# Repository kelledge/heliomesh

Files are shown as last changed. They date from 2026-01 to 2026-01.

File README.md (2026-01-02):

# Heliomesh


[Documentation](https://kelledge.github.io/heliomesh/)

Heliomesh is a growing collection of PCB designs that enable anyone to build robust solar-power
Meshtastic nodes.

As fun as it is to solder up a solution, these often end up being the weak point of any solution.
This project aims to provide fully integrated solutions that any one can order and pairs nicely
with the existing range of Meshtastic devices and enclosures.

## Contibuting
TODO

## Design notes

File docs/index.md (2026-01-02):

# Project Docs

## Boards
  - [xiao-harbor-breeze-60lm](projects/xiao-harbor-breeze-60lm/index.md)

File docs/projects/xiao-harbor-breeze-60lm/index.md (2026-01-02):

<script type="module" src="https://ajax.googleapis.com/ajax/libs/model-viewer/4.0.0/model-viewer.min.js"></script>
<script type="module" src="../../kicanvas.js"></script>

# XIAO Harbor Breeze 60 Lumen

## Documentation

### 3D Model
<model-viewer alt="" src="../../assets/projects/xiao-harbor-breeze-60lm/xiao-harbor-breeze-60lm-3D.glb" shadow-intensity="0" camera-controls touch-action="pan-y" exposure="0.5" style="display:block; height:auto; width:100%; max-width:100%; aspect-ratio:16/9;"></model-viewer>

### Schematic
<kicanvas-embed src="../../assets/projects/xiao-harbor-breeze-60lm/xiao-harbor-breeze-60lm.kicad_sch" controls="full"></kicanvas-embed>

### PCB
<kicanvas-embed src="../../assets/projects/xiao-harbor-breeze-60lm/xiao-harbor-breeze-60lm.kicad_pcb" controls="full"></kicanvas-embed>

## Documentation
 - [Interactive BOM](../../assets/projects/xiao-harbor-breeze-60lm/xiao-harbor-breeze-60lm-ibom.html)

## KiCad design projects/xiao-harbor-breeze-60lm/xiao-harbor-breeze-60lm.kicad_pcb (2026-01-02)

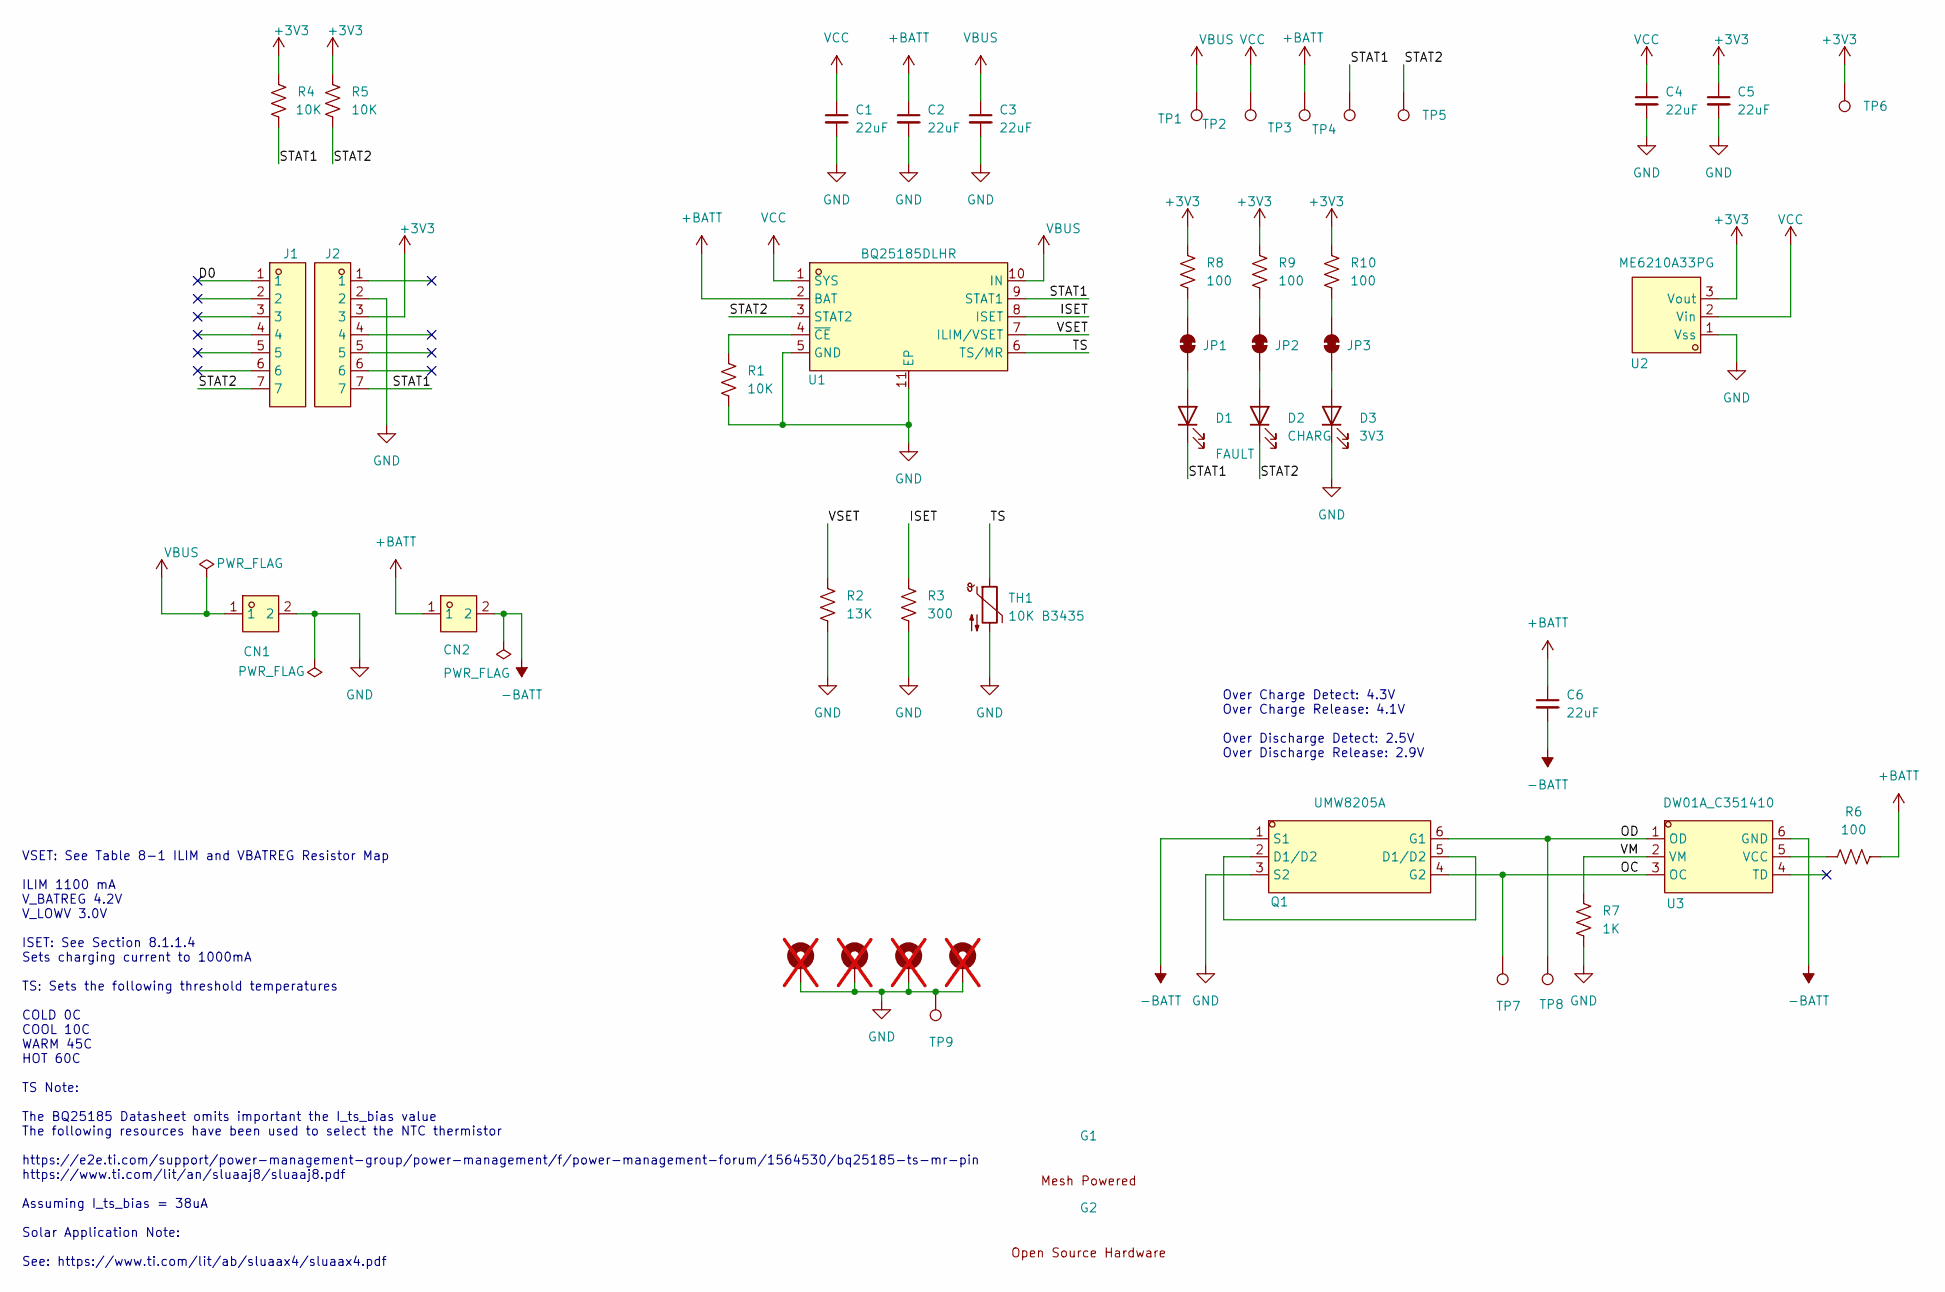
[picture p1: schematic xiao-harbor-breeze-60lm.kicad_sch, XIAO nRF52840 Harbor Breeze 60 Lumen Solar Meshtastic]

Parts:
C1, C2, C3, C4, C5, C6: 22uF; C_0805_2012Metric; JLCPCB PN C318688
CN1, CN2: XY122R-5.08-2P; CONN-TH_XY122R-5.08-2P; LCSC Part C784938
D1: FAULT; LED_0603_1608Metric; JLCPCB PN C965799
D2: CHARG; LED_0603_1608Metric; JLCPCB PN C965799
D3: 3V3; LED_0603_1608Metric; JLCPCB PN C965799
G1: mesh_pwrd_very_small
G2: oshw_very_small
H1, H2, H3, H4: MountingHole_Pad; MountingHole_3.2mm_M3_ISO7380_Pad; not fitted
J1, J2: 1165SDIG-07; HDR-TH_7P-P2.54-V-F; LCSC Part C2886701
JP1, JP2, JP3: SolderJumper_2_Bridged; SolderJumper-2_P1.3mm_Bridged_RoundedPad1.0x1.5mm
Q1: UMW8205A; SOT-23-6_L2.9-W1.6-P0.95-LS2.8-BL; LCSC Part C351449
R1, R4, R5: 10K; R_0603_1608Metric; JLCPCB PN C25804
R2: 13K; R_0603_1608Metric; JLCPCB PN C22797
R3: 300; R_0603_1608Metric; JLCPCB PN C23025
R6, R8, R9, R10: 100; R_0603_1608Metric; JLCPCB PN C22775
R7: 1K; R_0603_1608Metric; JLCPCB PN C21190
TH1: 10K B3435; R_0603_1608Metric; JLCPCB PN C153011
TP1, TP2, TP3, TP4, TP5, TP6, TP7, TP8, TP9: TestPoint; TestPoint_Pad_D1.5mm
U1: BQ25185DLHR; WSON-10_L2.2-W2.0-P0.40-BL-EP_TI_DLH0010A; LCSC Part C19725033
U2: ME6210A33PG; SOT-89_L4.5-W2.5-P1.50-LS4.2-BR; LCSC Part C85233
U3: DW01A_C351410; SOT-23-6_L2.9-W1.6-P0.95-LS2.8-BL; LCSC Part C351410

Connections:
+3V3: C5.1, J2.3, R4.1, R5.1, R8.1, R9.1, R10.1, TP6.1, U2.3 (Vout)
+BATT: C2.1, C6.1, CN2.1, R6.2, TP3.1, U1.2 (BAT)
-BATT: C6.2, CN2.2, Q1.1 (S1), U3.6 (GND)
/D0: J1.1
/ISET: R3.1, U1.8 (ISET)
/OC: Q1.4 (G2), TP7.1, U3.3 (OC)
/OD: Q1.6 (G1), TP8.1, U3.1 (OD)
/STAT1: D1.1 (K), J2.7, R4.2, TP4.1, U1.9 (STAT1)
/STAT2: D2.1 (K), J1.7, R5.2, TP5.1, U1.3 (STAT2)
/TS: TH1.1, U1.6 (TS/MR)
/VM: R7.1, U3.2 (VM)
/VSET: R2.1, U1.7 (ILIM/VSET)
GND: C1.2, C2.2, C3.2, C4.2, C5.2, CN1.2, D3.1 (K), H1.1, H2.1, H3.1, H4.1, J2.2, Q1.3 (S2), R1.2, R2.2, R3.2, R7.2, TH1.2, TP9.1, U1.5 (GND), U1.11 (EP), U2.1 (Vss)
unnamed: D1.2 (A), JP1.1 (A)
unnamed: D2.2 (A), JP2.1 (A)
unnamed: D3.2 (A), JP3.1 (A)
unnamed: JP1.2 (B), R8.2
unnamed: JP2.2 (B), R9.2
unnamed: JP3.2 (B), R10.2
unnamed: Q1.2 (D1/D2), Q1.5 (D1/D2)
unnamed: R1.1, U1.4 (~CE)
unnamed: R6.1, U3.5 (VCC)
VBUS: C3.1, CN1.1, TP1.1, U1.10 (IN)
VCC: C1.1, C4.1, TP2.1, U1.1 (SYS), U2.2 (Vin)

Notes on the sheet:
VSET: See Table 8-1 ILIM and VBATREG Resistor Map ILIM 1100 mA V_BATREG 4.2V V_LOWV 3.0V ISET: See Section 8.1.1.4 Sets charging current to 1000mA TS: Sets the following threshold temperatures COLD 0C COOL 10C WARM 45C HOT 60C TS Note: The BQ25185 Datasheet omits important the I_ts_bias value The f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
Over Charge Detect: 4.3V Over Charge Release: 4.1V Over Discharge Detect: 2.5V Over Discharge Release: 2.9V

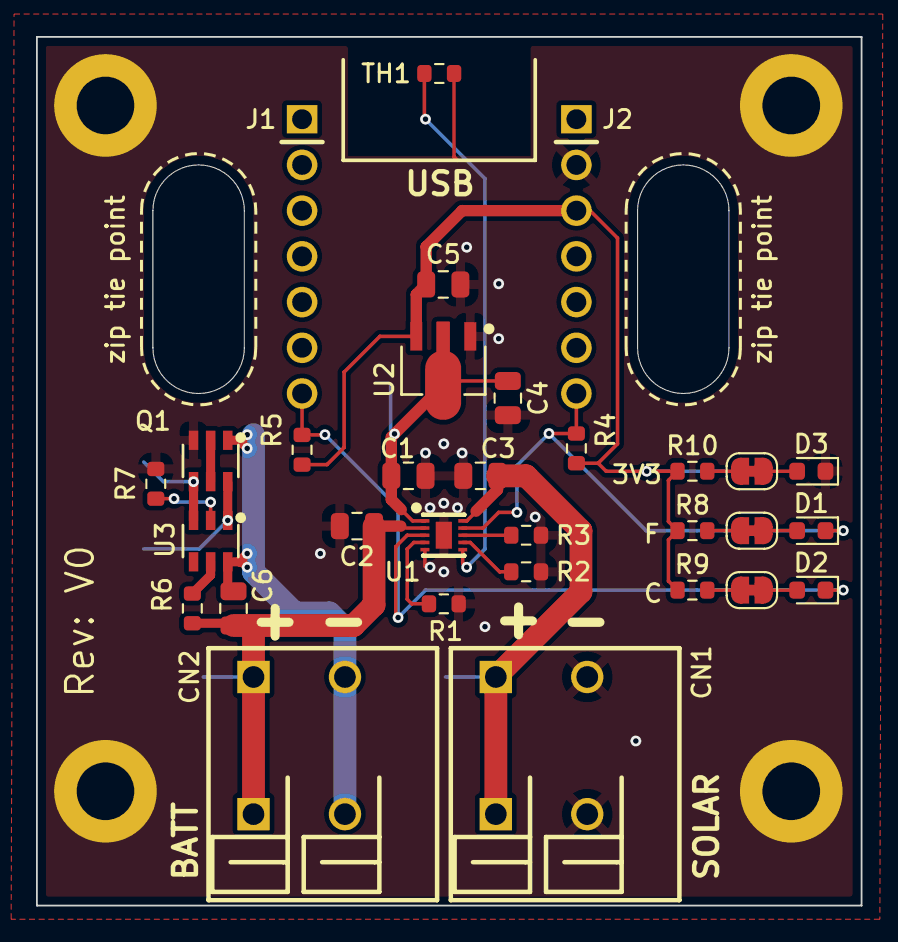
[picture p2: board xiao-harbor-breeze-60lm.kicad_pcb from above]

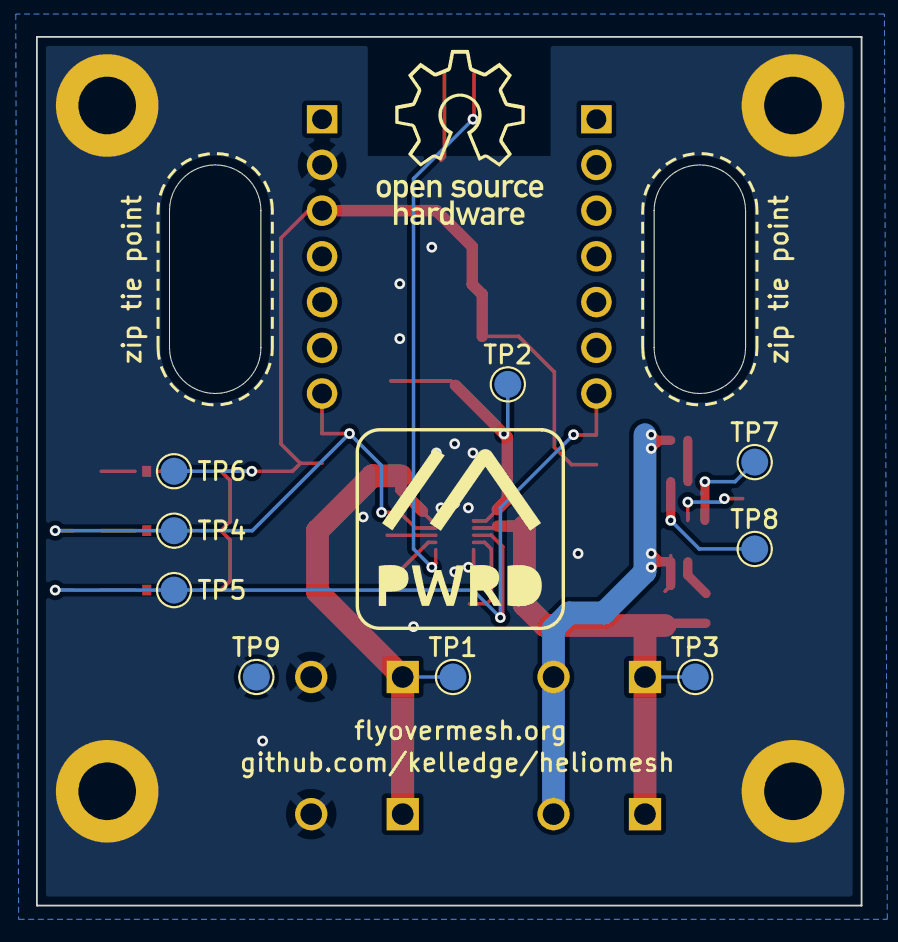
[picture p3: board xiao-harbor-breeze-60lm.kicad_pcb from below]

Board: 2 copper layers, 45.8 x 48.3 mm, 46 parts (11 on the bottom side), 23 nets.

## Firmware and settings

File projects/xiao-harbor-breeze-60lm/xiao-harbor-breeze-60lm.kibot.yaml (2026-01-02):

kibot:
  version: 1

global:
  dir: ../../build/xiao-harbor-breeze-60lm
  environment:
    symbols: /usr/share/kicad/symbols
    footprints: /usr/share/kicad/footprints
    models_3d: /usr/share/kicad/3dmodels
    templates: /usr/share/kicad/templates
  filters:
      - number: 9

preflight:
  drc:
    dir: reports
    dont_stop: false
    format: HTML,JSON
  erc:
    dir: reports
    dont_stop: false
    format: HTML,JSON

groups:
  - name: test
    comment: Check-run outputs
    preflights:
      - drc
      - erc
  - name: doc
    comment: Documentation outputs
    outputs:
      - pdf_sch_print
      - pcb_svg
      - export_3d
      - ibom
      - info
  - name: fab
    comment: Fabrication outputs
    outputs:
      - gerber
      - excellon
  - name: man
    comment: Manufacture outputs
    outputs:
      - jlcpcb_position
      - jlcpcb_bom
      - jlcpcb_zip

outputs:

# 
# Documentation
#
- name: 'pdf_sch_print'
  comment: 'Schematic PDF export'
  type: 'pdf_sch_print'
  dir: +/documentation
  options:
    # [boolean=true] Generate with all hierarchical sheets
    all_pages: true
    # [boolean=false] Use the background color from the `color_theme` (KiCad 6)
    background_color: false
    # [string=''] Color theme used, this must exist in the KiCad config (KiCad 6)
    color_theme: ''
    # [string='KiCad Font'] Name for the default font. Only for KiCad 9 and newer
    default_font: 'KiCad Font'
    # [string|list(string)='_null'] Name of the filter to mark components as not fitted.
    # Is a short-cut to use for simple cases where a variant is an overkill.
    # Can be used to fine-tune a variant for a particular output that needs extra filtering done before the
    # variant
    dnf_filter: '_null'
    # [string|list(string)='_null'] Name of the filter to exclude components from processing.
    # Is a short-cut to use for simple cases where a variant is an overkill.
    # Can be used to fine-tune a variant for a particular output that needs extra filtering done before the
    # variant
    exclude_filter: '_null'
    # [boolean=true] Include the frame and title block
    frame: true
    # [boolean=false] Generate a monochromatic output
    monochrome: false
    # [string='%f-%i%I%v.%x'] Filename for the output PDF (%i=schematic, %x=pdf). Affected by global options
    output: '%f-%i%I%v.%x'
    # [string|list(string)='_null'] Name of the filter to transform fields before applying other filters.
    # Is a short-cut to use for simple cases where a variant is an overkill.
    # Can be used to fine-tune a variant for a particular output that needs extra filtering done before the
    # variant
    pre_transform: '_null'
    # [string=''] Worksheet file (.kicad_wks) to use. Leave empty to use the one specified in the project.
    # This option works only when you print the toplevel sheet of a project and the project
    # file is available
    sheet_reference_layout: ''
    # [string=''] Text used to replace the sheet title. %VALUE expansions are allowed.
    # If it starts with `+` the text is concatenated
    title: ''
    # [string=''] Board variant to apply.
    # Not fitted components are crossed
    variant: ''
    
- name: pcb_svg
  comment: 'Board SVG export'
  type: pcbdraw
  dir: +/documentation
  options:
    # [boolean=true] The `show_components` list is added to the list of components indicated by the variant (fitted and not
    # excluded).
    # This is the old behavior, but isn't intuitive because the `show_components` meaning changes when a variant
    # is used. In this mode you should avoid using `show_components` and variants.
    # To get a more coherent behavior disable this option, and `none` will always be `none`.
    # Also `all` will be what the variant says
    add_to_variant: true
    # [boolean=false] Render the bottom side of the board (default is top side)
    bottom: false
    # [string|list(string)='_null'] Name of the filter to mark components as not fitted.
    # Is a short-cut to use for simple cases where a variant is an overkill.
    # Can be used to fine-tune a variant for a particular output that needs extra filtering done before the
    # variant
    dnf_filter: '_null'
    # [number=300] [10,1200] Dots per inch (resolution) of the generated image
    dpi: 300
    # [string|list(string)='_null'] Name of the filter to exclude components from processing.
    # Is a short-cut to use for simple cases where a variant is an overkill.
    # Can be used to fine-tune a variant for a particular output that needs extra filtering done before the
    # variant
    exclude_filter: '_null'
    # [string='svg'] [svg,png,jpg,bmp] Output format. Only used if no `output` is specified
    format: 'svg'
    # [list(string)=[]] List of components to highlight. Filter expansion is also allowed here,
    # see `show_components`
    highlight: []
    # [list(string)] List of libraries
    libs: ['KiCAD-base']
    # [number|dict=0] Margin around the generated image [mm].
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

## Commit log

2025-12-31 lib: Add DW01A and UMW8205A
    These two parts are the essential parts to the battery cell safety
    disconnect
2025-12-31 Add low voltage and over voltage protection
    This part is a final safety net for battery charage management.
    It is configured to have a low voltage cutoff of 2.5V and an over
    voltage cutoff of 4.3V.
    These values are comfortably outside the range of the change controller
    thresholds, but still within the ranges generally accepted to avoid
    permanent cell damage.
    If for some reason we over charge or over discharge, this part will do a
    low side disconnect of the battery from the rest of the system.
    lib: Add simple logos
    Currently unused, but are available.
    See:
    * https://meshtastic.org/docs/legal/licensing-and-trademark/#community-project-logos-m-powered--m-pwrd
    * https://oshwa.org/resou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
    [xiao-harbor-breeze-60lm.kicad_pcb, xiao-harbor-breeze-60lm.kicad_sch]
2025-12-31 Add ziptie mounting slots
    [xiao-harbor-breeze-60lm.kicad_pcb, xiao-harbor-breeze-60lm.kicad_sch]
2025-12-31 Use horizontally oriented spring terminals
    [xiao-harbor-breeze-60lm.kicad_pcb, xiao-harbor-breeze-60lm.kicad_sch]
2025-12-31 Organize project symbol and footprints
2025-12-31 Add test points and status LEDs
    LEDs allow simple confirmation of the board state. Cut their traces
    after testing to save around 20mW of power draw.
    Added test points to important signals to speed up diagnosing any issues
    with the initial design.
    Minor update to README.md
    [xiao-harbor-breeze-60lm.kicad_pcb, xiao-harbor-breeze-60lm.kicad_sch]
2025-12-31 Add user documented LED jumpers
    Indicates to users that the LEDs are optional and documents how and
    where to cut to conserve power.
    [xiao-harbor-breeze-60lm.kicad_pcb, xiao-harbor-breeze-60lm.kicad_sch]
2025-12-31 Drop graphics from BOM
    [xiao-harbor-breeze-60lm.kicad_pcb, xiao-harbor-breeze-60lm.kicad_sch]
2026-01-02 Add additional documentation artifacts
    * Exports glb 3D model: This is a format suitable for use with
    https://github.com/google/model-viewer
    * Exports kicanvas for interactive web view of schematic and pcb
    * Initialize MkDocs for static documentation site generator
    * Add custom `on_files` hook to move kibot assets to generated site
    * Extend workflow to publish pages
2026-01-02 Fix GLB output; Vendor all libraries
    The kicad binaries for Ubuntu 24.04 are linked against a buggy version
    of OCCT. The most direct solution here was simply to upgrade to Ubuntu 25.04.
    Additionally all referenced libraries are now vendored under lib/. This
    ensures that there are no conflicts between the container definition and
    the host.
    Due to this, the entire lib/ directory is now tracked in git lfs.
    [xiao-harbor-breeze-60lm.kicad_pcb, xiao-harbor-breeze-60lm.kicad_sch]
2026-01-02 Drop workflow path predicate; Attempt to solve documentation link
    Dropping the workflow path predicate for the moment. It has no use
    currently while only a single project is hosted.
2026-01-02 Add zip-tie PCB documentation
    Documents the purpose of the PCB cutout regions. Intended for users to
    pass a zip-tie through and around to secure the XIAO development kit.
    [xiao-harbor-breeze-60lm.kicad_pcb, xiao-harbor-breeze-60lm.kicad_sch]
